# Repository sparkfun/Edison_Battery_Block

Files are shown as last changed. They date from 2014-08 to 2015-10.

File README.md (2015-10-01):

SparkFun Block for Intel Edison - Battery/Power
=================================================

SparkFun Block for Intel Edison - Battery/Power

[*SparkFun Block for Intel Edison - Battery/Power (DEV-13037)*](https://www.sparkfun.com/products/13037)

Go wireless with Edison!  
The Battery board brings a single cell LiPo Charger and 400mah battery to power an Intel Edision and expansion cards.  
The Battery board can be used with an external battery to increase runtime.  Simply plug in a micro USB cable to charge.  
The power switch removes the battery from the Edison while allowing it to charge via the microUSB cable.

Repository Contents
-------------------
* **/Hardware** - Eagle design files (.brd, .sch)
* **/Production** - Production panel files (.brd)

Documentation
--------------
* **[Hookup Guide](https://learn.sparkfun.com/tutorials/sparkfun-blocks-for-intel-edison---battery-block)** - Basic hookup guide for the battery/power block.
* **[SparkFun Fritzing repo](https://github.com/sparkfun/Fritzing_Parts)** - Fritzing diagrams for SparkFun products.
* **[SparkFun 3D Model repo](https://github.com/sparkfun/3D_Models)** - 3D models of SparkFun products. 

Product Versions
----------------
* [Battery Block](https://www.sparkfun.com/products/13037)- Battery block.
* [Power Block](https://www.sparkfun.com/products/13727)- Battery block without lipo battery installed. 

License Information
-------------------

This product is _**open source**_! 

Please review the LICENSE.md file for license information. 

If you have any questions or concerns on licensing, please contact techsupport@sparkfun.com.

Distributed as-is; no warranty is given.

- Your friends at SparkFun.

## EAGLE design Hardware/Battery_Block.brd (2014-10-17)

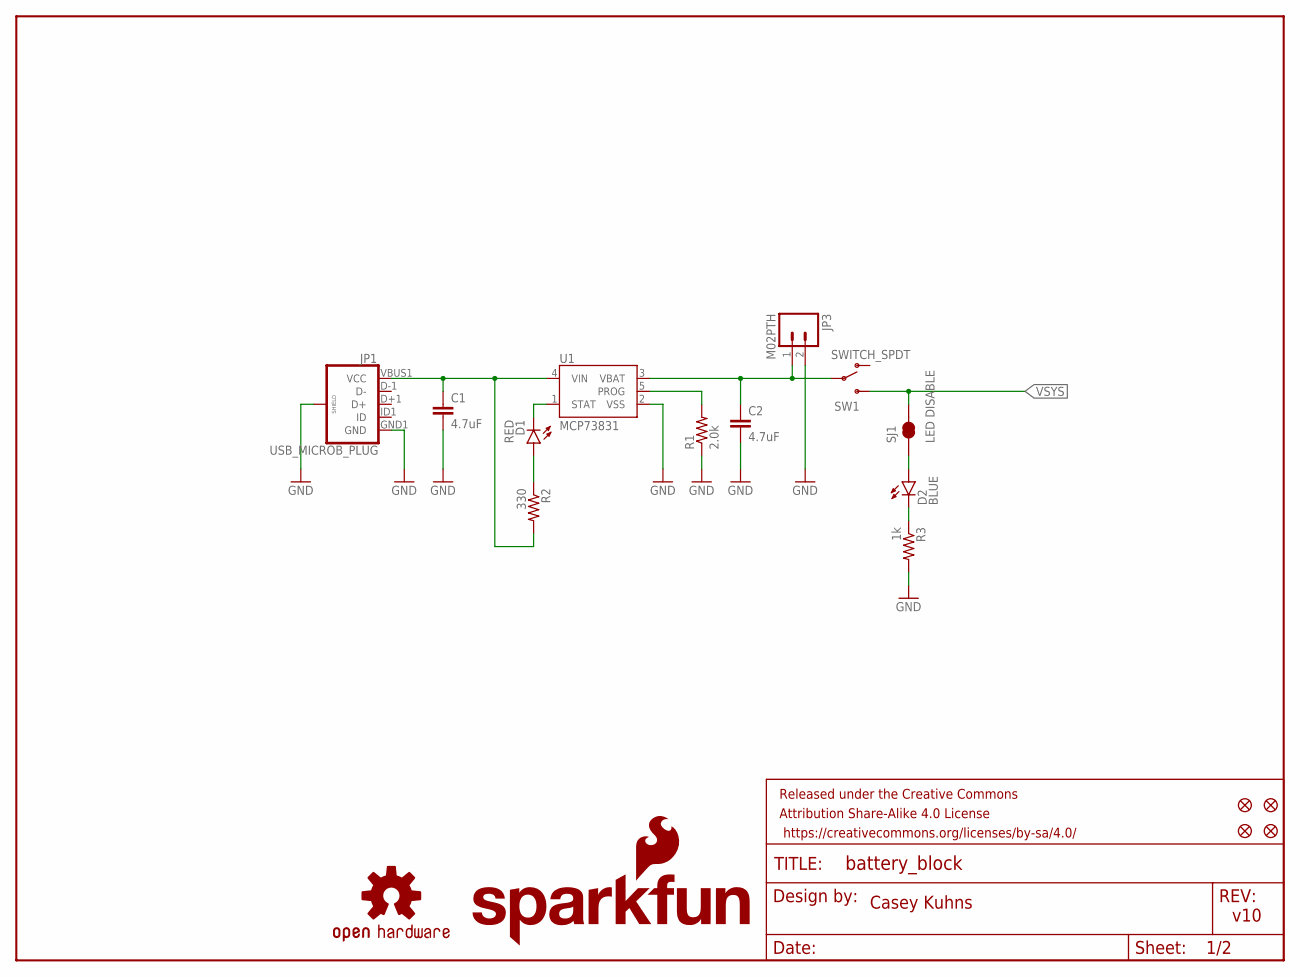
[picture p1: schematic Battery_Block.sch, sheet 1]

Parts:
C1, C2: 4.7uF; 0603-CAP
D1: RED; LED-0603
D2: BLUE; LED-0603
FID1, FID2, FID3, FID4: FIDUCIAL1X2; FIDUCIAL-1X2
FRAME1: FRAME-LETTER; CREATIVE_COMMONS
JP1: USB_MICROB_PLUG; USB-B-MICRO-SMD_V03
JP3: M02PTH; 1X02
LOGO1: OSHW-LOGOS; OSHW-LOGO-S
LOGO4: SFE_LOGO_NAME_FLAME.1_INCH; SFE_LOGO_NAME_FLAME_.1
R1: 2.0k; 0603-RES
R2: 330; 0603-RES
R3: 1k; 0603-RES
SJ1: LED DISABLE; PAD-JUMPER-2-NC_BY_TRACE_YES_SILK
SW1: SWITCH_SPDT; KPS-1290
U1: MCP73831; SOT23-5

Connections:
GND: C1.2, C2.2, JP1.GND1 (GND), JP1.SHIELD1 (SHIELD), JP1.SHIELD2 (SHIELD), JP1.SHIELD3 (SHIELD), JP3.2, R1.1, R3.2, U1.2 (VSS); also elsewhere on the board
unnamed: D2.C, R3.1
unnamed: R1.2, U1.5 (PROG)
unnamed: D1.A, R2.1
unnamed: D1.C, U1.1 (STAT)
unnamed: D2.A, SJ1.1
VBAT: C2.1, JP3.1, SW1.P, U1.3 (VBAT)
VIN: C1.1, JP1.VBUS1 (VCC), R2.2, U1.4 (VIN)
VSYS: SJ1.2, SW1.S; also elsewhere on the board

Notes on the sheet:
Casey Kuhns
v10

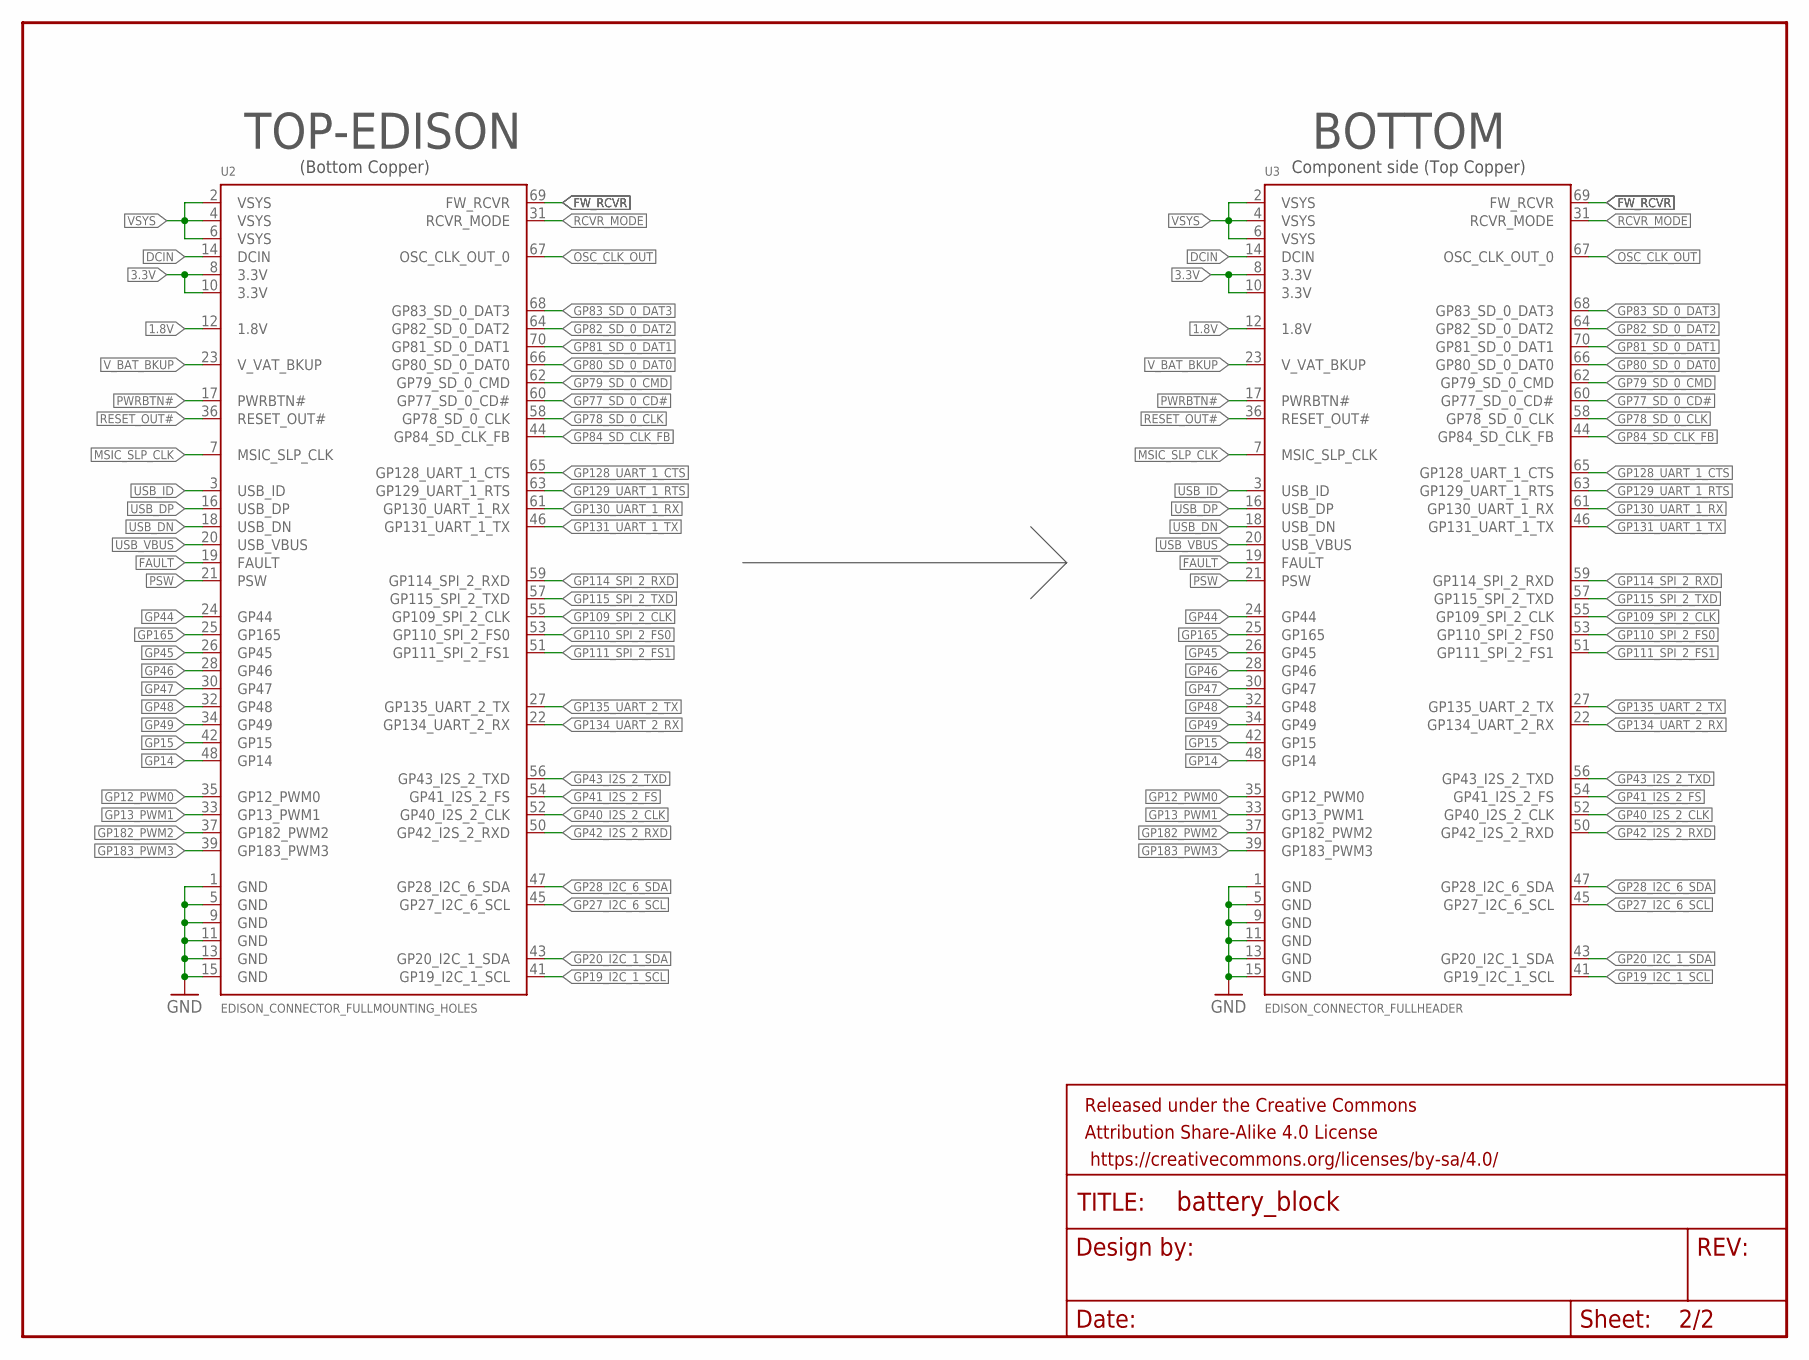
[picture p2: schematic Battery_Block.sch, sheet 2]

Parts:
FRAME2: FRAME-LETTER; CREATIVE_COMMONS
U2: EDISON_CONNECTOR_FULLMOUNTING_HOLES; EDISON_DAUGHTER
U3: EDISON_CONNECTOR_FULLHEADER; DF40C-70DP-0.4(51)

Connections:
1.8V: U2.12 (1.8V), U3.12 (1.8V)
3.3V: U2.8 (3.3V), U2.10 (3.3V), U3.8 (3.3V), U3.10 (3.3V)
DCIN: U2.14 (DCIN), U3.14 (DCIN)
FAULT: U2.19 (FAULT), U3.19 (FAULT)
FW_RCVR: U2.69 (FW_RCVR), U3.69 (FW_RCVR)
GND: U2.1 (GND), U2.5 (GND), U2.9 (GND), U2.11 (GND), U2.13 (GND), U2.15 (GND), U3.1 (GND), U3.5 (GND), U3.9 (GND), U3.11 (GND), U3.13 (GND), U3.15 (GND); also elsewhere on the board
GP12_PWM0: U2.35 (GP12_PWM0), U3.35 (GP12_PWM0)
GP13_PWM1: U2.33 (GP13_PWM1), U3.33 (GP13_PWM1)
GP14: U2.48 (GP14), U3.48 (GP14)
GP15: U2.42 (GP15), U3.42 (GP15)
GP19_I2C_1_SCL: U2.41 (GP19_I2C_1_SCL), U3.41 (GP19_I2C_1_SCL)
GP20_I2C_1_SDA: U2.43 (GP20_I2C_1_SDA), U3.43 (GP20_I2C_1_SDA)
GP27_I2C_6_SCL: U2.45 (GP27_I2C_6_SCL), U3.45 (GP27_I2C_6_SCL)
GP28_I2C_6_SDA: U2.47 (GP28_I2C_6_SDA), U3.47 (GP28_I2C_6_SDA)
GP40_I2S_2_CLK: U2.52 (GP40_I2S_2_CLK), U3.52 (GP40_I2S_2_CLK)
GP41_I2S_2_FS: U2.54 (GP41_I2S_2_FS), U3.54 (GP41_I2S_2_FS)
GP42_I2S_2_RXD: U2.50 (GP42_I2S_2_RXD), U3.50 (GP42_I2S_2_RXD)
GP43_I2S_2_TXD: U2.56 (GP43_I2S_2_TXD), U3.56 (GP43_I2S_2_TXD)
GP44: U2.24 (GP44), U3.24 (GP44)
GP45: U2.26 (GP45), U3.26 (GP45)
GP46: U2.28 (GP46), U3.28 (GP46)
GP47: U2.30 (GP47), U3.30 (GP47)
GP48: U2.32 (GP48), U3.32 (GP48)
GP49: U2.34 (GP49), U3.34 (GP49)
GP77_SD_0_CD#: U2.60 (GP77_SD_0_CD#), U3.60 (GP77_SD_0_CD#)
GP78_SD_0_CLK: U2.58 (GP78_SD_0_CLK), U3.58 (GP78_SD_0_CLK)
GP79_SD_0_CMD: U2.62 (GP79_SD_0_CMD), U3.62 (GP79_SD_0_CMD)
GP80_SD_0_DAT0: U2.66 (GP80_SD_0_DAT0), U3.66 (GP80_SD_0_DAT0)
GP81_SD_0_DAT1: U2.70 (GP81_SD_0_DAT1), U3.70 (GP81_SD_0_DAT1)
GP82_SD_0_DAT2: U2.64 (GP82_SD_0_DAT2), U3.64 (GP82_SD_0_DAT2)
GP83_SD_0_DAT3: U2.68 (GP83_SD_0_DAT3), U3.68 (GP83_SD_0_DAT3)
GP84_SD_CLK_FB: U2.44 (GP84_SD_CLK_FB), U3.44 (GP84_SD_CLK_FB)
GP109_SPI_2_CLK: U2.55 (GP109_SPI_2_CLK), U3.55 (GP109_SPI_2_CLK)
GP110_SPI_2_FS0: U2.53 (GP110_SPI_2_FS0), U3.53 (GP110_SPI_2_FS0)
GP111_SPI_2_FS1: U2.51 (GP111_SPI_2_FS1), U3.51 (GP111_SPI_2_FS1)
GP114_SPI_2_RXD: U2.59 (GP114_SPI_2_RXD), U3.59 (GP114_SPI_2_RXD)
GP115_SPI_2_TXD: U2.57 (GP115_SPI_2_TXD), U3.57 (GP115_SPI_2_TXD)
GP128_UART_1_CTS: U2.65 (GP128_UART_1_CTS), U3.65 (GP128_UART_1_CTS)
GP129_UART_1_RTS: U2.63 (GP129_UART_1_RTS), U3.63 (GP129_UART_1_RTS)
GP130_UART_1_RX: U2.61 (GP130_UART_1_RX), U3.61 (GP130_UART_1_RX)
GP131_UART_1_TX: U2.46 (GP131_UART_1_TX), U3.46 (GP131_UART_1_TX)
GP134_UART_2_RX: U2.22 (GP134_UART_2_RX), U3.22 (GP134_UART_2_RX)
GP135_UART_2_TX: U2.27 (GP135_UART_2_TX), U3.27 (GP135_UART_2_TX)
GP165: U2.25 (GP165), U3.25 (GP165)
GP182_PWM2: U2.37 (GP182_PWM2), U3.37 (GP182_PWM2)
GP183_PWM3: U2.39 (GP183_PWM3), U3.39 (GP183_PWM3)
MSIC_SLP_CLK: U2.7 (MSIC_SLP_CLK), U3.7 (MSIC_SLP_CLK)
OSC_CLK_OUT: U2.67 (OSC_CLK_OUT_0), U3.67 (OSC_CLK_OUT_0)
PSW: U2.21 (PSW), U3.21 (PSW)
PWRBTN#: U2.17 (PWRBTN#), U3.17 (PWRBTN#)
RCVR_MODE: U2.31 (RCVR_MODE), U3.31 (RCVR_MODE)
RESET_OUT#: U2.36 (RESET_OUT#), U3.36 (RESET_OUT#)
USB_DN: U2.18 (USB_DN), U3.18 (USB_DN)
USB_DP: U2.16 (USB_DP), U3.16 (USB_DP)
USB_ID: U2.3 (USB_ID), U3.3 (USB_ID)
USB_VBUS: U2.20 (USB_VBUS), U3.20 (USB_VBUS)
VSYS: U2.2 (VSYS), U2.4 (VSYS), U2.6 (VSYS), U3.2 (VSYS), U3.4 (VSYS), U3.6 (VSYS); also elsewhere on the board
V_BAT_BKUP: U2.23 (V_VAT_BKUP), U3.23 (V_VAT_BKUP)

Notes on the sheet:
TOP-EDISON
BOTTOM
Component side (Top Copper)
(Bottom Copper)

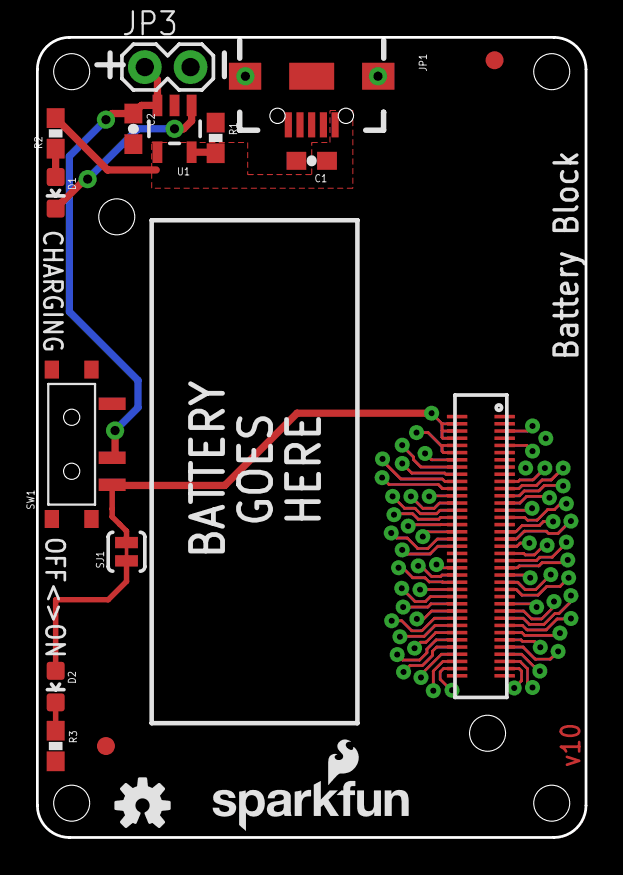
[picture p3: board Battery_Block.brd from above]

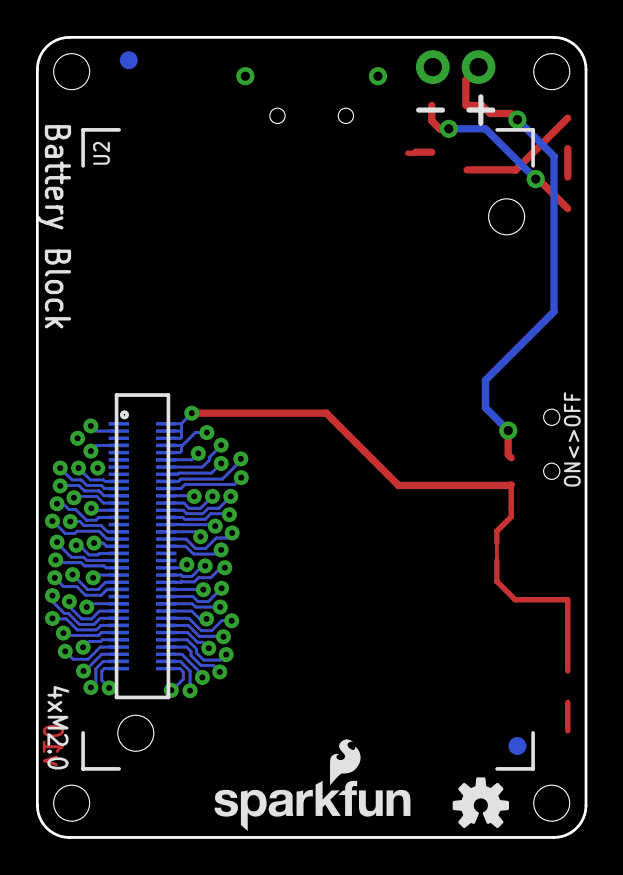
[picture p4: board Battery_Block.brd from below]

Board: 2 copper layers, 30.5 x 44.5 mm, 24 parts (6 on the bottom side), 65 nets.

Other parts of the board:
LOGO2: OSHW-LOGOS; OSHW-LOGO-S
LOGO3: SFE_LOGO_NAME_FLAME.1_INCH; SFE_LOGO_NAME_FLAME_.1

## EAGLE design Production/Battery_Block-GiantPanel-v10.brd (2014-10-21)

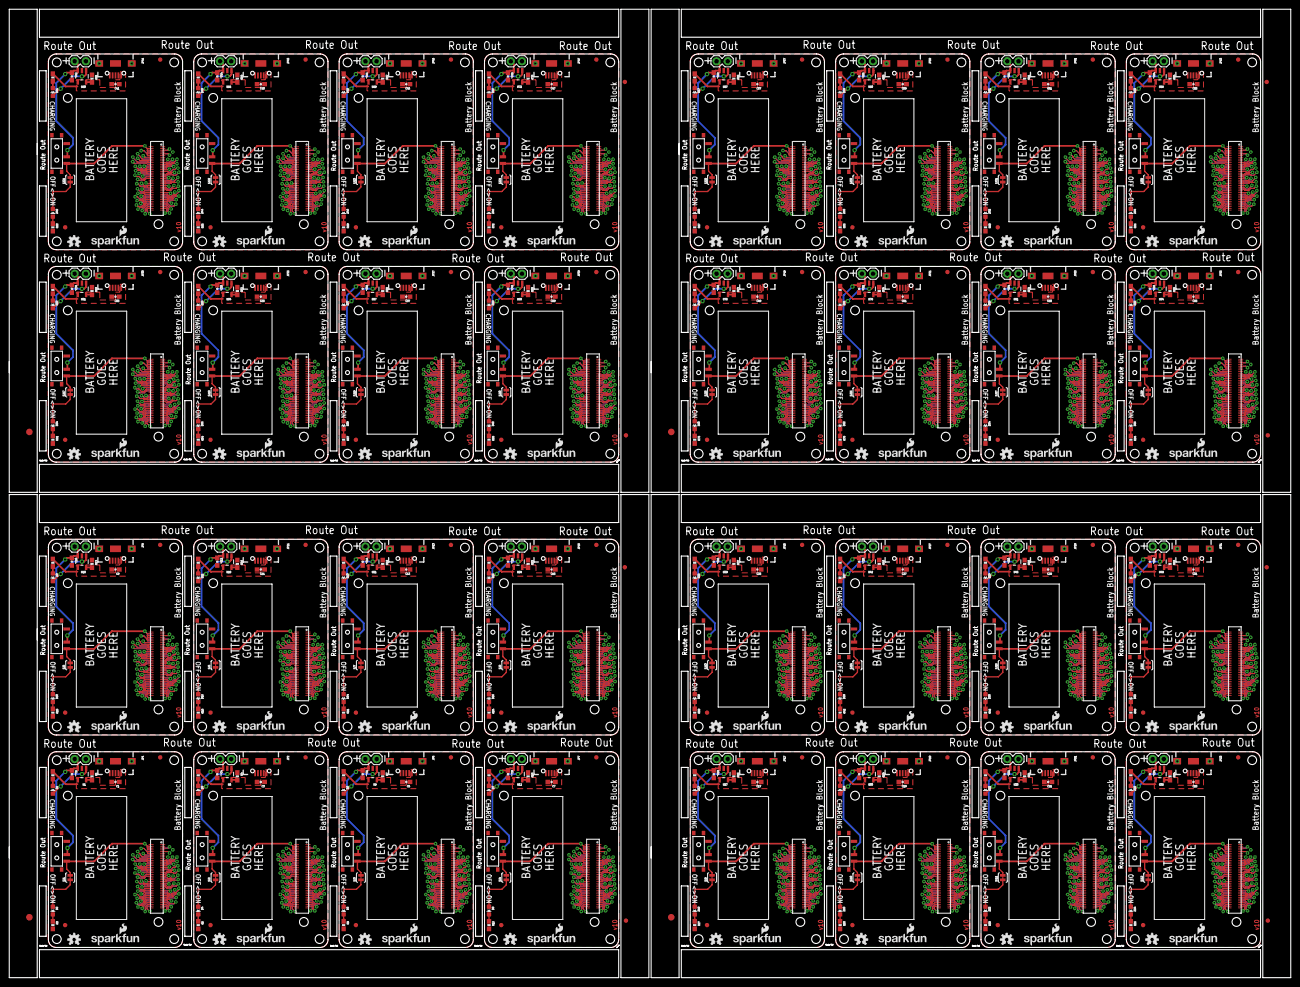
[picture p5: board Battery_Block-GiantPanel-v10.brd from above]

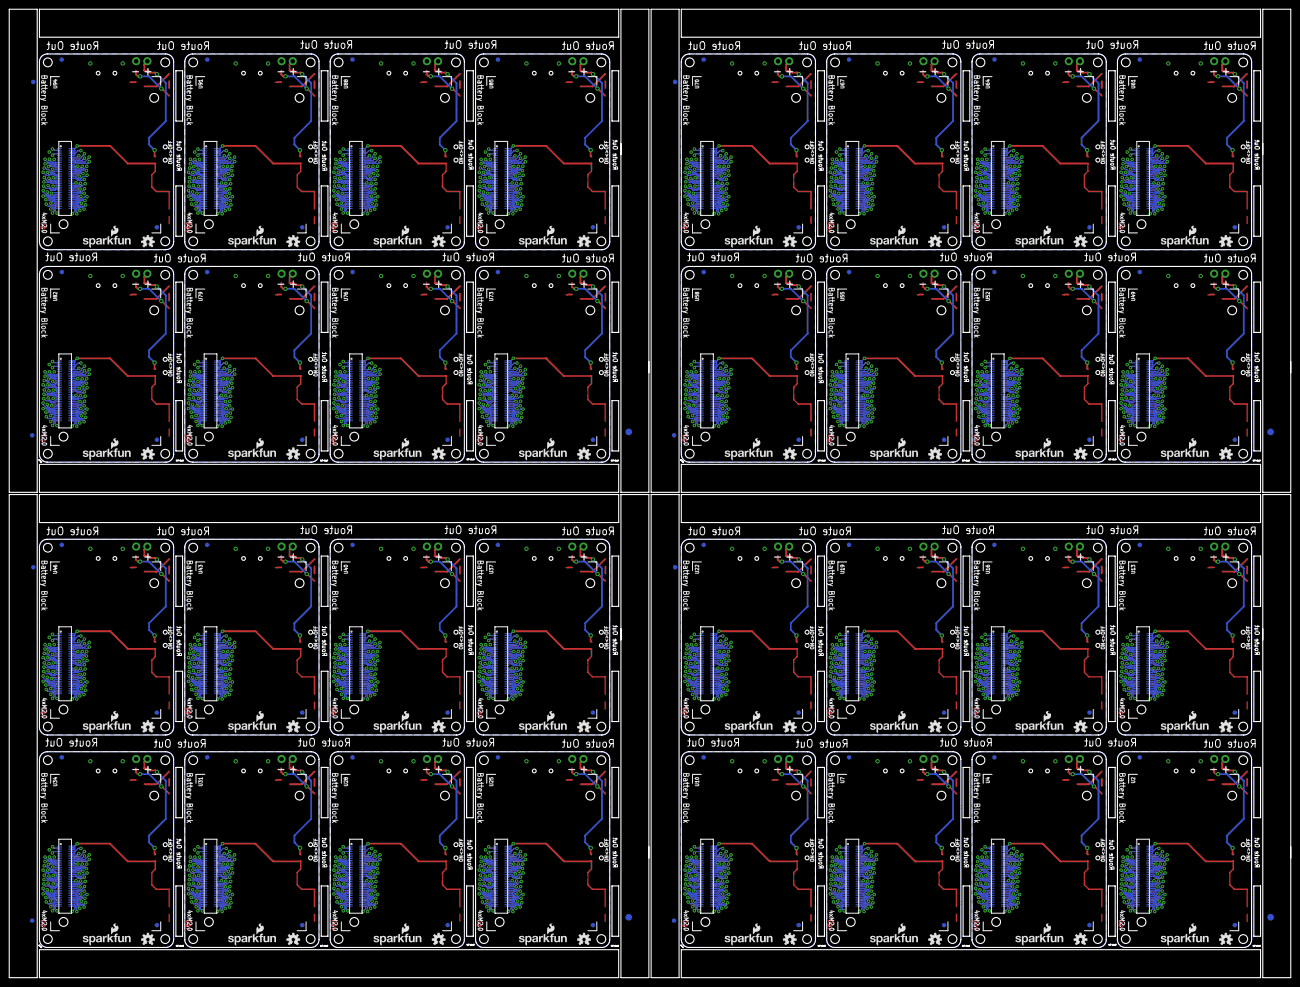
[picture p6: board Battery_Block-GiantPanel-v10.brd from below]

Board: 2 copper layers, 291.1 x 220.0 mm, 728 parts (204 on the bottom side), 2080 nets.

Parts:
C1, C2, C3, C4, C5, C6, C7, C8, C9, C10, C11, C12, C13, C14, C15, C16, C17, C18, C19, C20, C21, C22, C23, C24, C25, C26, C27, C28, C29, C30, C31, C32, C33, C34, C35, C36, C37, C38, C39, C40, C41, C42, C43, C44, C45, C46, C47, C48, C49, C50, C51, C52, C53, C54, C55, C56, C57, C58, C59, C60, C61, C62, C63, C64: 4.7uF; 0603-CAP
D1, D3, D5, D7, D9, D11, D13, D15, D17, D19, D21, D23, D25, D27, D29, D31, D33, D35, D37, D39, D41, D43, D45, D47, D49, D51, D53, D55, D57, D59, D61, D63: RED; LED-0603
D2, D4, D6, D8, D10, D12, D14, D16, D18, D20, D22, D24, D26, D28, D30, D32, D34, D36, D38, D40, D42, D44, D46, D48, D50, D52, D54, D56, D58, D60, D62, D64: BLUE; LED-0603
E$1, E$2, E$9, E$10, E$15, E$16, E$21, E$22: FIDUCIAL-1.5X3
E$3, E$4, E$5, E$6, E$7, E$8, E$11, E$12, E$13, E$14, E$17, E$18, E$19, E$20, E$23, E$24: FIDUCIAL-1X2
FID1, FID2, FID3, FID4, FID5, FID6, FID7, FID8, FID9, FID10, FID11, FID12, FID13, FID14, FID15, FID16, FID17, FID18, FID19, FID20, FID21, FID22, FID23, FID24, FID25, FID26, FID27, FID28, FID29, FID30, FID31, FID32, FID33, FID34, FID35, FID36, FID37, FID38, FID39, FID40, FID41, FID42, FID43, FID44, FID45, FID46, FID47, FID48, FID49, FID50, FID51, FID52, FID53, FID54, FID55, FID56, FID57, FID58, FID59, FID60, FID61, FID62, FID63, FID64, FID65, FID66, FID67, FID68, FID69, FID70, FID71, FID72, FID73, FID74, FID75, FID76, FID77, FID78, FID79, FID80, FID81, FID82, FID83, FID84, FID85, FID86, FID87, FID88, FID89, FID90, FID91, FID92, FID93, FID94, FID95, FID96, FID97, FID98, FID99, FID100, FID101, FID102, FID103, FID104, FID105, FID106, FID107, FID108, FID109, FID110, FID111, FID112, FID113, FID114, FID115, FID116, FID117, FID118, FID119, FID120, FID121, FID122, FID123, FID124, FID125, FID126, FID127, FID128: FIDUCIAL1X2; FIDUCIAL-1X2
JP1, JP2, JP5, JP7, JP9, JP11, JP13, JP15, JP17, JP19, JP21, JP23, JP25, JP27, JP29, JP31, JP33, JP35, JP37, JP39, JP41, JP43, JP45, JP47, JP49, JP51, JP53, JP55, JP57, JP59, JP61, JP63: USB_MICROB_PLUG; USB-B-MICRO-SMD_V03
JP3, JP4, JP6, JP8, JP10, JP12, JP14, JP16, JP18, JP20, JP22, JP24, JP26, JP28, JP30, JP32, JP34, JP36, JP38, JP40, JP42, JP44, JP46, JP48, JP50, JP52, JP54, JP56, JP58, JP60, JP62, JP64: M02PTH; 1X02
LOGO1, LOGO2, LOGO5, LOGO7, LOGO9, LOGO11, LOGO13, LOGO15, LOGO17, LOGO19, LOGO21, LOGO23, LOGO25, LOGO27, LOGO29, LOGO31, LOGO33, LOGO35, LOGO37, LOGO39, LOGO41, LOGO43, LOGO45, LOGO47, LOGO49, LOGO51, LOGO53, LOGO55, LOGO57, LOGO59, LOGO61, LOGO63, LOGO65, LOGO67, LOGO69, LOGO71, LOGO73, LOGO75, LOGO77, LOGO79, LOGO81, LOGO83, LOGO85, LOGO87, LOGO89, LOGO91, LOGO93, LOGO95, LOGO97, LOGO99, LOGO101, LOGO103, LOGO105, LOGO107, LOGO109, LOGO111, LOGO113, LOGO115, LOGO117, LOGO119, LOGO121, LOGO123, LOGO125, LOGO127: OSHW-LOGOS; OSHW-LOGO-S
LOGO3, LOGO4, LOGO6, LOGO8, LOGO10, LOGO12, LOGO14, LOGO16, LOGO18, LOGO20, LOGO22, LOGO24, LOGO26, LOGO28, LOGO30, LOGO32, LOGO34, LOGO36, LOGO38, LOGO40, LOGO42, LOGO44, LOGO46, LOGO48, LOGO50, LOGO52, LOGO54, LOGO56, LOGO58, LOGO60, LOGO62, LOGO64, LOGO66, LOGO68, LOGO70, LOGO72, LOGO74, LOGO76, LOGO78, LOGO80, LOGO82, LOGO84, LOGO86, LOGO88, LOGO90, LOGO92, LOGO94, LOGO96, LOGO98, LOGO100, LOGO102, LOGO104, LOGO106, LOGO108, LOGO110, LOGO112, LOGO114, LOGO116, LOGO118, LOGO120, LOGO122, LOGO124, LOGO126, LOGO128: SFE_LOGO_NAME_FLAME.1_INCH; SFE_LOGO_NAME_FLAME_.1
R1, R4, R7, R10, R13, R16, R19, R22, R25, R28, R31, R34, R37, R40, R43, R46, R49, R52, R55, R58, R61, R64, R67, R70, R73, R76, R79, R82, R85, R88, R91, R94: 2.0k; 0603-RES
R2, R5, R8, R11, R14, R17, R20, R23, R26, R29, R32, R35, R38, R41, R44, R47, R50, R53, R56, R59, R62, R65, R68, R71, R74, R77, R80, R83, R86, R89, R92, R95: 330; 0603-RES
R3, R6, R9, R12, R15, R18, R21, R24, R27, R30, R33, R36, R39, R42, R45, R48, R51, R54, R57, R60, R63, R66, R69, R72, R75, R78, R81, R84, R87, R90, R93, R96: 1k; 0603-RES
SJ1, SJ2, SJ3, SJ4, SJ5, SJ6, SJ7, SJ8, SJ9, SJ10, SJ11, SJ12, SJ13, SJ14, SJ15, SJ16, SJ17, SJ18, SJ19, SJ20, SJ21, SJ22, SJ23, SJ24, SJ25, SJ26, SJ27, SJ28, SJ29, SJ30, SJ31, SJ32: LED DISABLE; PAD-JUMPER-2-NC_BY_TRACE_YES_SILK
SW1, SW2, SW3, SW4, SW5, SW6, SW7, SW8, SW9, SW10, SW11, SW12, SW13, SW14, SW15, SW16, SW17, SW18, SW19, SW20, SW21, SW22, SW23, SW24, SW25, SW26, SW27, SW28, SW29, SW30, SW31, SW32: SWITCH_SPDT; KPS-1290
U1, U6, U9, U12, U15, U18, U21, U24, U27, U30, U33, U36, U39, U42, U45, U48, U51, U54, U57, U60, U63, U66, U69, U72, U75, U78, U81, U84, U87, U90, U93, U96: MCP73831; SOT23-5
U2, U4, U7, U10, U13, U16, U19, U22, U25, U28, U31, U34, U37, U40, U43, U46, U49, U52, U55, U58, U61, U64, U67, U70, U73, U76, U79, U82, U85, U88, U91, U94: EDISON_CONNECTOR_FULLMOUNTING_HOLES; EDISON_DAUGHTER
U3, U5, U8, U11, U14, U17, U20, U23, U26, U29, U32, U35, U38, U41, U44, U47, U50, U53, U56, U59, U62, U65, U68, U71, U74, U77, U80, U83, U86, U89, U92, U95: EDISON_CONNECTOR_FULLHEADER; DF40C-70DP-0.4(51)

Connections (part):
1.8V: U2.12, U3.12
1.8V1: U4.12, U5.12
1.8V2: U7.12, U8.12
1.8V3: U10.12, U11.12
1.8V4: U13.12, U14.12
1.8V5: U16.12, U17.12
1.8V6: U19.12, U20.12
1.8V7: U22.12, U23.12
1.8V8: U25.12, U26.12
1.8V9: U28.12, U29.12
1.8V10: U31.12, U32.12
1.8V11: U34.12, U35.12
1.8V12: U37.12, U38.12
1.8V13: U40.12, U41.12
1.8V14: U43.12, U44.12
1.8V15: U46.12, U47.12
1.8V16: U49.12, U50.12
1.8V17: U52.12, U53.12
1.8V18: U55.12, U56.12
1.8V19: U58.12, U59.12
1.8V20: U61.12, U62.12
1.8V21: U64.12, U65.12
1.8V22: U67.12, U68.12
1.8V23: U70.12, U71.12
1.8V24: U73.12, U74.12
1.8V25: U76.12, U77.12
1.8V26: U79.12, U80.12
1.8V27: U82.12, U83.12
1.8V28: U85.12, U86.12
1.8V29: U88.12, U89.12
1.8V30: U91.12, U92.12
1.8V31: U94.12, U95.12
3.3V: U2.8, U2.10, U3.8, U3.10
3.3V1: U4.8, U4.10, U5.8, U5.10
3.3V2: U7.8, U7.10, U8.8, U8.10
3.3V3: U10.8, U10.10, U11.8, U11.10
3.3V4: U13.8, U13.10, U14.8, U14.10
3.3V5: U16.8, U16.10, U17.8, U17.10
3.3V6: U19.8, U19.10, U20.8, U20.10
3.3V7: U22.8, U22.10, U23.8, U23.10
3.3V8: U25.8, U25.10, U26.8, U26.10
3.3V9: U28.8, U28.10, U29.8, U29.10
3.3V10: U31.8, U31.10, U32.8, U32.10
3.3V11: U34.8, U34.10, U35.8, U35.10
3.3V12: U37.8, U37.10, U38.8, U38.10
3.3V13: U40.8, U40.10, U41.8, U41.10
3.3V14: U43.8, U43.10, U44.8, U44.10
3.3V15: U46.8, U46.10, U47.8, U47.10
3.3V16: U49.8, U49.10, U50.8, U50.10
3.3V17: U52.8, U52.10, U53.8, U53.10
3.3V18: U55.8, U55.10, U56.8, U56.10
3.3V19: U58.8, U58.10, U59.8, U59.10
3.3V20: U61.8, U61.10, U62.8, U62.10
3.3V21: U64.8, U64.10, U65.8, U65.10
3.3V22: U67.8, U67.10, U68.8, U68.10
3.3V23: U70.8, U70.10, U71.8, U71.10
3.3V24: U73.8, U73.10, U74.8, U74.10
3.3V25: U76.8, U76.10, U77.8, U77.10
3.3V26: U79.8, U79.10, U80.8, U80.10
3.3V27: U82.8, U82.10, U83.8, U83.10
3.3V28: U85.8, U85.10, U86.8, U86.10
3.3V29: U88.8, U88.10, U89.8, U89.10
3.3V30: U91.8, U91.10, U92.8, U92.10
3.3V31: U94.8, U94.10, U95.8, U95.10
DCIN: U2.14, U3.14
DCIN1: U4.14, U5.14
DCIN2: U7.14, U8.14
DCIN3: U10.14, U11.14
DCIN4: U13.14, U14.14
DCIN5: U16.14, U17.14
DCIN6: U19.14, U20.14
DCIN7: U22.14, U23.14
DCIN8: U25.14, U26.14
DCIN9: U28.14, U29.14
DCIN10: U31.14, U32.14
DCIN11: U34.14, U35.14
DCIN12: U37.14, U38.14
DCIN13: U40.14, U41.14
DCIN14: U43.14, U44.14
DCIN15: U46.14, U47.14
DCIN16: U49.14, U50.14
DCIN17: U52.14, U53.14
DCIN18: U55.14, U56.14
DCIN19: U58.14, U59.14
DCIN20: U61.14, U62.14
DCIN21: U64.14, U65.14
DCIN22: U67.14, U68.14
DCIN23: U70.14, U71.14
DCIN24: U73.14, U74.14
DCIN25: U76.14, U77.14
DCIN26: U79.14, U80.14
DCIN27: U82.14, U83.14
DCIN28: U85.14, U86.14
DCIN29: U88.14, U89.14
DCIN30: U91.14, U92.14
DCIN31: U94.14, U95.14
FAULT: U2.19, U3.19
FAULT1: U4.19, U5.19
FAULT2: U7.19, U8.19
FAULT3: U10.19, U11.19
FAULT4: U13.19, U14.19
FAULT5: U16.19, U17.19
FAULT6: U19.19, U20.19
FAULT7: U22.19, U23.19
FAULT8: U25.19, U26.19
FAULT9: U28.19, U29.19
FAULT10: U31.19, U32.19
FAULT11: U34.19, U35.19
FAULT12: U37.19, U38.19
FAULT13: U40.19, U41.19
FAULT14: U43.19, U44.19
FAULT15: U46.19, U47.19
FAULT16: U49.19, U50.19
FAULT17: U52.19, U53.19
FAULT18: U55.19, U56.19
FAULT19: U58.19, U59.19
FAULT20: U61.19, U62.19
FAULT21: U64.19, U65.19
FAULT22: U67.19, U68.19
FAULT23: U70.19, U71.19
FAULT24: U73.19, U74.19
FAULT25: U76.19, U77.19
FAULT26: U79.19, U80.19
FAULT27: U82.19, U83.19
FAULT28: U85.19, U86.19
FAULT29: U88.19, U89.19
FAULT30: U91.19, U92.19
FAULT31: U94.19, U95.19
FW_RCVR: U2.69, U3.69
FW_RCVR1: U4.69, U5.69
FW_RCVR2: U7.69, U8.69
FW_RCVR3: U10.69, U11.69
FW_RCVR4: U13.69, U14.69
FW_RCVR5: U16.69, U17.69
FW_RCVR6: U19.69, U20.69
FW_RCVR7: U22.69, U23.69
FW_RCVR8: U25.69, U26.69
FW_RCVR9: U28.69, U29.69
FW_RCVR10: U31.69, U32.69
FW_RCVR11: U34.69, U35.69
FW_RCVR12: U37.69, U38.69
FW_RCVR13: U40.69, U41.69
FW_RCVR14: U43.69, U44.69
FW_RCVR15: U46.69, U47.69
FW_RCVR16: U49.69, U50.69
FW_RCVR17: U52.69, U53.69
FW_RCVR18: U55.69, U56.69
FW_RCVR19: U58.69, U59.69
FW_RCVR20: U61.69, U62.69
FW_RCVR21: U64.69, U65.69
FW_RCVR22: U67.69, U68.69
FW_RCVR23: U70.69, U71.69
FW_RCVR24: U73.69, U74.69
FW_RCVR25: U76.69, U77.69
FW_RCVR26: U79.69, U80.69
FW_RCVR27: U82.69, U83.69
FW_RCVR28: U85.69, U86.69
FW_RCVR29: U88.69, U89.69
FW_RCVR30: U91.69, U92.69
FW_RCVR31: U94.69, U95.69
GND: C1.2, C2.2, JP1.GND1, JP1.SHIELD1, JP1.SHIELD2, JP1.SHIELD3, JP3.2, R1.1, R3.2, U1.2, U2.1, U2.5, U2.9, U2.11, U2.13, U2.15, U3.1, U3.5, U3.9, U3.11, U3.13, U3.15
GND1: C3.2, C4.2, JP2.GND1, JP2.SHIELD1, JP2.SHIELD2, JP2.SHIELD3, JP4.2, R4.1, R6.2, U4.1, U4.5, U4.9, U4.11, U4.13, U4.15, U5.1, U5.5, U5.9, U5.11, U5.13, U5.15, U6.2
GND2: C5.2, C6.2, JP5.GND1, JP5.SHIELD1, JP5.SHIELD2, JP5.SHIELD3, JP6.2, R7.1, R9.2, U7.1, U7.5, U7.9, U7.11, U7.13, U7.15, U8.1, U8.5, U8.9, U8.11, U8.13, U8.15, U9.2
GND3: C7.2, C8.2, JP7.GND1, JP7.SHIELD1, JP7.SHIELD2, JP7.SHIELD3, JP8.2, R10.1, R12.2, U10.1, U10.5, U10.9, U10.11, U10.13, U10.15, U11.1, U11.5, U11.9, U11.11, U11.13, U11.15, U12.2
GND4: C9.2, C10.2, JP9.GND1, JP9.SHIELD1, JP9.SHIELD2, JP9.SHIELD3, JP10.2, R13.1, R15.2, U13.1, U13.5, U13.9, U13.11, U13.13, U13.15, U14.1, U14.5, U14.9, U14.11, U14.13, U14.15, U15.2
GND5: C11.2, C12.2, JP11.GND1, JP11.SHIELD1, JP11.SHIELD2, JP11.SHIELD3, JP12.2, R16.1, R18.2, U16.1, U16.5, U16.9, U16.11, U16.13, U16.15, U17.1, U17.5, U17.9, U17.11, U17.13, U17.15, U18.2
GND6: C13.2, C14.2, JP13.GND1, JP13.SHIELD1, JP13.SHIELD2, JP13.SHIELD3, JP14.2, R19.1, R21.2, U19.1, U19.5, U19.9, U19.11, U19.13, U19.15, U20.1, U20.5, U20.9, U20.11, U20.13, U20.15, U21.2
GND7: C15.2, C16.2, JP15.GND1, JP15.SHIELD1, JP15.SHIELD2, JP15.SHIELD3, JP16.2, R22.1, R24.2, U22.1, U22.5, U22.9, U22.11, U22.13, U22.15, U23.1, U23.5, U23.9, U23.11, U23.13, U23.15, U24.2
GND8: C17.2, C18.2, JP17.GND1, JP17.SHIELD1, JP17.SHIELD2, JP17.SHIELD3, JP18.2, R25.1, R27.2, U25.1, U25.5, U25.9, U25.11, U25.13, U25.15, U26.1, U26.5, U26.9, U26.11, U26.13, U26.15, U27.2
GND9: C19.2, C20.2, JP19.GND1, JP19.SHIELD1, JP19.SHIELD2, JP19.SHIELD3, JP20.2, R28.1, R30.2, U28.1, U28.5, U28.9, U28.11, U28.13, U28.15, U29.1, U29.5, U29.9, U29.11, U29.13, U29.15, U30.2
GND10: C21.2, C22.2, JP21.GND1, JP21.SHIELD1, JP21.SHIELD2, JP21.SHIELD3, JP22.2, R31.1, R33.2, U31.1, U31.5, U31.9, U31.11, U31.13, U31.15, U32.1, U32.5, U32.9, U32.11, U32.13, U32.15, U33.2
GND11: C23.2, C24.2, JP23.GND1, JP23.SHIELD1, JP23.SHIELD2, JP23.SHIELD3, JP24.2, R34.1, R36.2, U34.1, U34.5, U34.9, U34.11, U34.13, U34.15, U35.1, U35.5, U35.9, U35.11, U35.13, U35.15, U36.2
GND12: C25.2, C26.2, JP25.GND1, JP25.SHIELD1, JP25.SHIELD2, JP25.SHIELD3, JP26.2, R37.1, R39.2, U37.1, U37.5, U37.9, U37.11, U37.13, U37.15, U38.1, U38.5, U38.9, U38.11, U38.13, U38.15, U39.2
GND13: C27.2, C28.2, JP27.GND1, JP27.SHIELD1, JP27.SHIELD2, JP27.SHIELD3, JP28.2, R40.1, R42.2, U40.1, U40.5, U40.9, U40.11, U40.13, U40.15, U41.1, U41.5, U41.9, U41.11, U41.13, U41.15, U42.2
GND14: C29.2, C30.2, JP29.GND1, JP29.SHIELD1, JP29.SHIELD2, JP29.SHIELD3, JP30.2, R43.1, R45.2, U43.1, U43.5, U43.9, U43.11, U43.13, U43.15, U44.1, U44.5, U44.9, U44.11, U44.13, U44.15, U45.2
GND15: C31.2, C32.2, JP31.GND1, JP31.SHIELD1, JP31.SHIELD2, JP31.SHIELD3, JP32.2, R46.1, R48.2, U46.1, U46.5, U46.9, U46.11, U46.13, U46.15, U47.1, U47.5, U47.9, U47.11, U47.13, U47.15, U48.2
GND16: C33.2, C34.2, JP33.GND1, JP33.SHIELD1, JP33.SHIELD2, JP33.SHIELD3, JP34.2, R49.1, R51.2, U49.1, U49.5, U49.9, U49.11, U49.13, U49.15, U50.1, U50.5, U50.9, U50.11, U50.13, U50.15, U51.2
GND17: C35.2, C36.2, JP35.GND1, JP35.SHIELD1, JP35.SHIELD2, JP35.SHIELD3, JP36.2, R52.1, R54.2, U52.1, U52.5, U52.9, U52.11, U52.13, U52.15, U53.1, U53.5, U53.9, U53.11, U53.13, U53.15, U54.2
GND18: C37.2, C38.2, JP37.GND1, JP37.SHIELD1, JP37.SHIELD2, JP37.SHIELD3, JP38.2, R55.1, R57.2, U55.1, U55.5, U55.9, U55.11, U55.13, U55.15, U56.1, U56.5, U56.9, U56.11, U56.13, U56.15, U57.2
GND19: C39.2, C40.2, JP39.GND1, JP39.SHIELD1, JP39.SHIELD2, JP39.SHIELD3, JP40.2, R58.1, R60.2, U58.1, U58.5, U58.9, U58.11, U58.13, U58.15, U59.1, U59.5, U59.9, U59.11, U59.13, U59.15, U60.2
GND20: C41.2, C42.2, JP41.GND1, JP41.SHIELD1, JP41.SHIELD2, JP41.SHIELD3, JP42.2, R61.1, R63.2, U61.1, U61.5, U61.9, U61.11, U61.13, U61.15, U62.1, U62.5, U62.9, U62.11, U62.13, U62.15, U63.2
GND21: C43.2, C44.2, JP43.GND1, JP43.SHIELD1, JP43.SHIELD2, JP43.SHIELD3, JP44.2, R64.1, R66.2, U64.1, U64.5, U64.9, U64.11, U64.13, U64.15, U65.1, U65.5, U65.9, U65.11, U65.13, U65.15, U66.2
GND22: C45.2, C46.2, JP45.GND1, JP45.SHIELD1, JP45.SHIELD2, JP45.SHIELD3, JP46.2, R67.1, R69.2, U67.1, U67.5, U67.9, U67.11, U67.13, U67.15, U68.1, U68.5, U68.9, U68.11, U68.13, U68.15, U69.2
GND23: C47.2, C48.2, JP47.GND1, JP47.SHIELD1, JP47.SHIELD2, JP47.SHIELD3, JP48.2, R70.1, R72.2, U70.1, U70.5, U70.9, U70.11, U70.13, U70.15, U71.1, U71.5, U71.9, U71.11, U71.13, U71.15, U72.2
GND24: C49.2, C50.2, JP49.GND1, JP49.SHIELD1, JP49.SHIELD2, JP49.SHIELD3, JP50.2, R73.1, R75.2, U73.1, U73.5, U73.9, U73.11, U73.13, U73.15, U74.1, U74.5, U74.9, U74.11, U74.13, U74.15, U75.2
GND25: C51.2, C52.2, JP51.GND1, JP51.SHIELD1, JP51.SHIELD2, JP51.SHIELD3, JP52.2, R76.1, R78.2, U76.1, U76.5, U76.9, U76.11, U76.13, U76.15, U77.1, U77.5, U77.9, U77.11, U77.13, U77.15, U78.2
GND26: C53.2, C54.2, JP53.GND1, JP53.SHIELD1, JP53.SHIELD2, JP53.SHIELD3, JP54.2, R79.1, R81.2, U79.1, U79.5, U79.9, U79.11, U79.13, U79.15, U80.1, U80.5, U80.9, U80.11, U80.13, U80.15, U81.2
GND27: C55.2, C56.2, JP55.GND1, JP55.SHIELD1, JP55.SHIELD2, JP55.SHIELD3, JP56.2, R82.1, R84.2, U82.1, U82.5, U82.9, U82.11, U82.13, U82.15, U83.1, U83.5, U83.9, U83.11, U83.13, U83.15, U84.2
GND28: C57.2, C58.2, JP57.GND1, JP57.SHIELD1, JP57.SHIELD2, JP57.SHIELD3, JP58.2, R85.1, R87.2, U85.1, U85.5, U85.9, U85.11, U85.13, U85.15, U86.1, U86.5, U86.9, U86.11, U86.13, U86.15, U87.2
GND29: C59.2, C60.2, JP59.GND1, JP59.SHIELD1, JP59.SHIELD2, JP59.SHIELD3, JP60.2, R88.1, R90.2, U88.1, U88.5, U88.9, U88.11, U88.13, U88.15, U89.1, U89.5, U89.9, U89.11, U89.13, U89.15, U90.2
GND30: C61.2, C62.2, JP61.GND1, JP61.SHIELD1, JP61.SHIELD2, JP61.SHIELD3, JP62.2, R91.1, R93.2, U91.1, U91.5, U91.9, U91.11, U91.13, U91.15, U92.1, U92.5, U92.9, U92.11, U92.13, U92.15, U93.2
GND31: C63.2, C64.2, JP63.GND1, JP63.SHIELD1, JP63.SHIELD2, JP63.SHIELD3, JP64.2, R94.1, R96.2, U94.1, U94.5, U94.9, U94.11, U94.13, U94.15, U95.1, U95.5, U95.9, U95.11, U95.13, U95.15, U96.2
GP1: U4.48, U5.48
GP2: U4.42, U5.42
GP3: U4.34, U5.34
GP4: U4.32, U5.32
GP5: U4.30, U5.30
GP6: U4.28, U5.28
GP7: U4.26, U5.26
GP8: U4.25, U5.25
GP9: U4.24, U5.24
GP10: U7.48, U8.48
GP11: U7.42, U8.42
GP12: U7.34, U8.34
GP12_PWM0: U2.35, U3.35
GP12_PWM1: U4.35, U5.35
GP12_PWM2: U7.35, U8.35
GP12_PWM3: U10.35, U11.35
GP12_PWM4: U13.35, U14.35
GP12_PWM5: U16.35, U17.35
GP12_PWM6: U19.35, U20.35
GP12_PWM7: U22.35, U23.35
GP12_PWM8: U25.35, U26.35
GP12_PWM9: U28.35, U29.35
GP12_PWM10: U31.35, U32.35
GP12_PWM11: U34.35, U35.35
GP12_PWM12: U37.35, U38.35
GP12_PWM13: U40.35, U41.35
GP12_PWM14: U43.35, U44.35
GP12_PWM15: U46.35, U47.35
GP12_PWM16: U49.35, U50.35
GP12_PWM17: U52.35, U53.35
GP12_PWM18: U55.35, U56.35
GP12_PWM19: U58.35, U59.35
GP12_PWM20: U61.35, U62.35
GP12_PWM21: U64.35, U65.35
GP12_PWM22: U67.35, U68.35
GP12_PWM23: U70.35, U71.35
GP12_PWM24: U73.35, U74.35
GP12_PWM25: U76.35, U77.35
GP12_PWM26: U79.35, U80.35
GP12_PWM27: U82.35, U83.35
GP12_PWM28: U85.35, U86.35
GP12_PWM29: U88.35, U89.35
GP12_PWM30: U91.35, U92.35
GP12_PWM31: U94.35, U95.35
GP13: U7.32, U8.32
GP13_PWM1: U2.33, U3.33
GP13_PWM2: U4.33, U5.33
GP13_PWM3: U7.33, U8.33
GP13_PWM4: U10.33, U11.33
GP13_PWM5: U13.33, U14.33
GP13_PWM6: U16.33, U17.33
GP13_PWM7: U19.33, U20.33
GP13_PWM8: U22.33, U23.33
GP13_PWM9: U25.33, U26.33
GP13_PWM10: U28.33, U29.33
GP13_PWM11: U31.33, U32.33
GP13_PWM12: U34.33, U35.33
GP13_PWM13: U37.33, U38.33
GP13_PWM14: U40.33, U41.33
GP13_PWM15: U43.33, U44.33
GP13_PWM16: U46.33, U47.33
GP13_PWM17: U49.33, U50.33
GP13_PWM18: U52.33, U53.33
GP13_PWM19: U55.33, U56.33
GP13_PWM20: U58.33, U59.33
GP13_PWM21: U61.33, U62.33
GP13_PWM22: U64.33, U65.33
GP13_PWM23: U67.33, U68.33
GP13_PWM24: U70.33, U71.33
GP13_PWM25: U73.33, U74.33
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

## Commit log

2014-08-09 Initial commit with templates
    [Mezzanine_Template.brd, Mezzanine_Template.sch]
2014-08-09 layout ready for review. Renamed boards
    [Mezzanine_Battery.brd, Mezzanine_Battery.sch]
2014-08-12 removed Edzzanine from name
    [Mezzanine_Battery.brd]
2014-09-20 corrected names, added DCIN, cleaned up dimensions
    [Mezzanine_Battery.brd, Mezzanine_Battery.sch]
2014-09-23 changed names of boards
    [Battery_Block.brd, Battery_Block.sch]
2014-09-25 file cleanup
    [Battery_Block.brd, Battery_Block.sch]
2014-10-16 Fix text rotation, go to v10
    [Battery_Block.brd, Battery_Block.sch]
2014-10-17 Add some silk, update fp, ready for reds
    [Battery_Block.brd, Battery_Block.sch]
2014-10-17 Ready for reds. Tweaked some silk positions, jumper position, on/off nomenclature No known to-do items
    [Battery_Block.brd]
2014-10-21 created v10 panels
    [Battery_Block-GiantPanel-v10.brd, Battery_Block-Panel-v10.brd]
2015-10-01 Updating README with product links, documentation links
    [Battery_Block-GiantPanel-v10.brd, Battery_Block-Panel-v10.brd]

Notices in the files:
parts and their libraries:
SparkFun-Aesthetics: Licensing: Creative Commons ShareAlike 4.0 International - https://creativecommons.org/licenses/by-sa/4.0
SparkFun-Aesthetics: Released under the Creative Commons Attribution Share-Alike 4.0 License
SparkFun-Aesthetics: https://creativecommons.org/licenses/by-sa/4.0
